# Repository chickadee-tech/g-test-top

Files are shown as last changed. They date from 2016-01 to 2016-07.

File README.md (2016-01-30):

# Chickadee Tech Generic Test Jig Top #
This is the top board to the generic test jig for Polystack **control** and **mod** boards.

## Documentation ##
See the [wiki](https://github.com/chickadee-tech/g-test-top/wiki) for documentation.

## Polystack ##
This board is part of the Polystack platform for modular microcontrol systems. More information on the platform can be found at [polystack.org](http://polystack.org).

## Support ##
If you need support with a board you own or have development questions please email support@chickadee.tech or check [chickadee.tech/support](https://chickadee.tech/support) for other ways to get support.

## Contributing ##
Please note that this project is released with a [Contributor Code of Conduct](CODE_OF_CONDUCT.md). By participating in this project you agree to abide by its terms.

### Setup ###
Components and footprints for PCB parts are not included in this repository. Instead, checkout the [chickadee-tech/kicad-libs](https://github.com/chickadee-tech/kicad-libs) repository in the same directory that this repository is checked out in. All part definitions should be relative so that they will load correctly.

### Pull requests ###
For fixes please submit a pull request to the original repository. After the pull request is merged, check the [Chickadee Tech Active Contributor Discount (ACD)](https://chickadee.tech/active-contributor) to see if you are eligible for a discount code to use on your next purchase.

### Derivatives ###
If developing your own version of the test jig top please remove all Chickadee Tech trademarks and follow the [CC-BY license](LICENSE). While not required, please consider open sourcing your modifications so others can learn from your improvements. If you do email support@chickadee.tech and we may choose to add your project to the ACD.

You may also license the Polystack logo for free by emailing support@chickadee.tech. We'll ask for your gerbers to ensure the design complies with specifications laid out [here](https://github.com/chickadee-tech/polystack/wiki) and provide written permission to use the trademark after compliance has been demonstrated.

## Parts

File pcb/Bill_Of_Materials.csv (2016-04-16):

part name | symbol | size (imp) | max current | unit price | units per build | units in stock | order total | Manufacturer ID | source url | datasheet | datasheet2
80 pin header | PORT_IN1 |  |  | $1.35 | 1 | 1 | $1.35 | DF40C-80DP-0.4V(51) | http://www.digikey.com/product-detail/en/DF40C-80DP-0.4V(51)/H11632CT-ND/1969511 | N | http://www.hirose.co.jp/cataloge_hp/ed_DF40_20140305.pdf |  | Total Base Cost | $7.13
side entry bottom 16pos 1mm | P1 |  |  | $0.92 | 1 | 0 | $0.92 | SFW16R-3STE1LF | http://www.digikey.com/product-detail/en/SFW16R-3STE1LF/609-1909-1-ND/1003194 | N |  | price ranges 1.40 - 2.50
1x8 mux | U1 | 16-VFQFN Exposed Pad |  | $0.43 | 1 | 1 | $0.43 | 74HC4051BQ,115 | http://www.digikey.com/product-detail/en/74HC4051BQ,115/568-7741-1-ND/2753885 | N | http://www.nxp.com/documents/data_sheet/74HC_HCT4051.pdf
1x16 mux | U2, U3, U4, U5 | 24-VFQFN Exposed Pad |  | $1.06 | 4 | 0 | $4.26 | 74HC4067BQ,118 | http://www.digikey.com/product-detail/en/74HC4067BQ,118/568-8885-1-ND/2813803 | N | http://www.nxp.com/documents/data_sheet/74HC_HCT4067.pdf
~3.5mm Spacer | Off Board |  |  | $0.08 | 1 | 81 | $0.08 | 908-140 | http://www.mouser.com/search/ProductDetail.aspx?R=0virtualkey0virtualkey908-140 | N | http://www.bivar.com/Portals/0/Products/d.ashx?f=/Portals/0/products/9XX-XXX.pdf
R 220 | R1, R2 | 603 |  | $0.00 | 2 | 493 | $0.01 | RC0603JR-07220RL | http://www.digikey.com/product-detail/en/yageo/RC0603JR-07220RL/311-220GRCT-ND/729688 | MF-RES-0603-220 | http://www.yageo.com/NewPortal/yageodocoutput?fileName=/pdf/R-Chip/PYu-RC_Group_51_RoHS_L_3.pdf
R 10k | R3, R4, R5, R6, R7, R8, R9, R10, R11 | 603 |  | $0.01 | 9 | 979 | $0.09 | RC0603FR-0710KL | http://www.digikey.com/product-detail/en/RC0603FR-0710KL/311-10.0KHRCT-ND/729827 | MF-RES-0603-10K | http://www.yageo.com/NewPortal/yageodocoutput?fileName=/pdf/R-Chip/PYu-RC_Group_51_RoHS_L_3.pdf

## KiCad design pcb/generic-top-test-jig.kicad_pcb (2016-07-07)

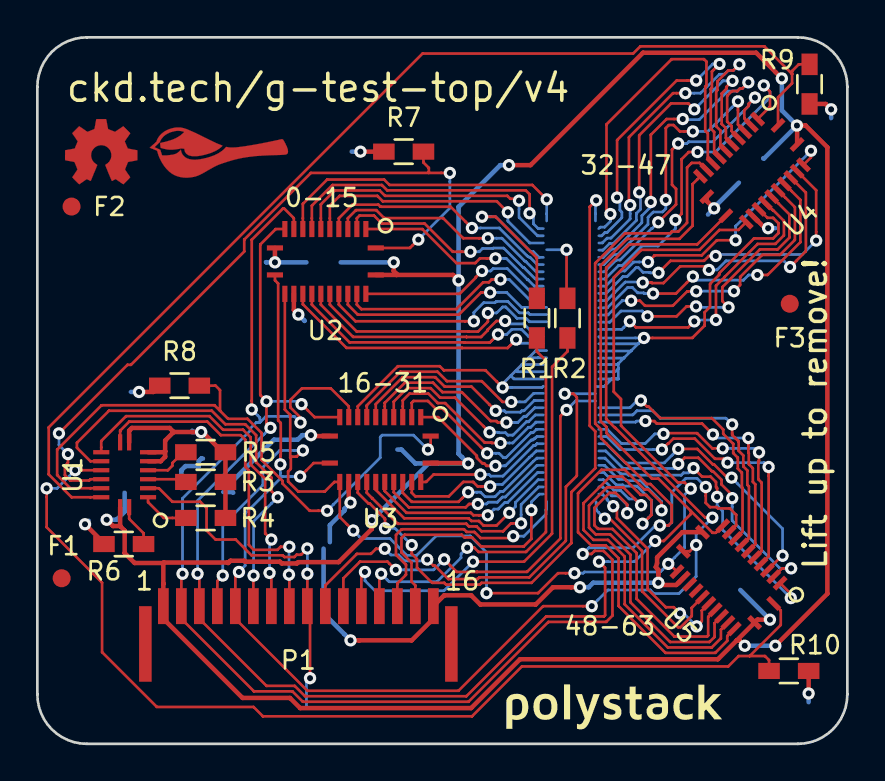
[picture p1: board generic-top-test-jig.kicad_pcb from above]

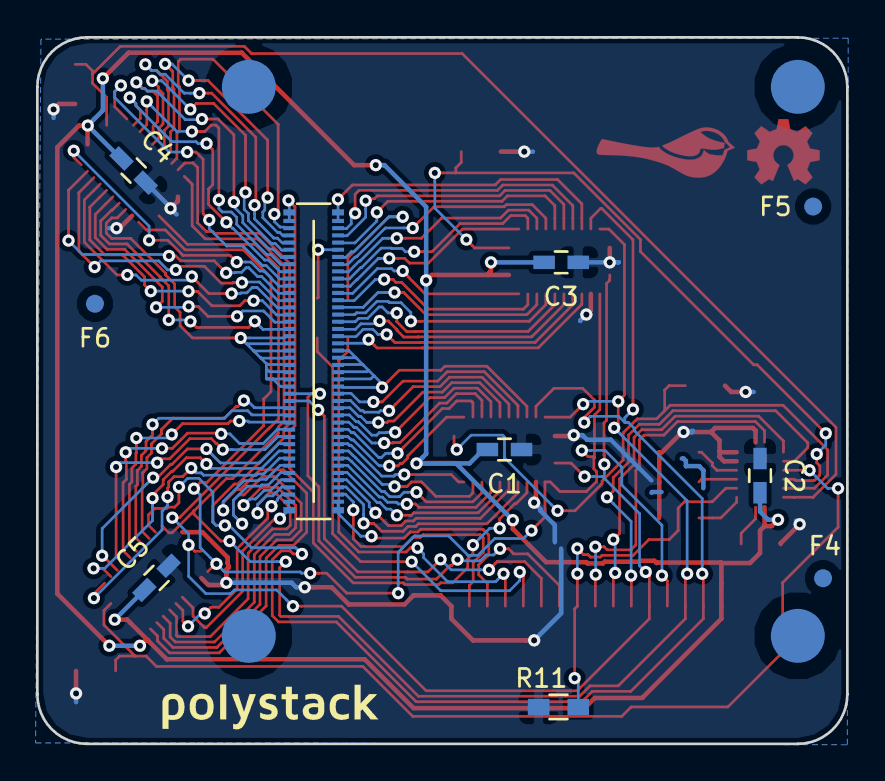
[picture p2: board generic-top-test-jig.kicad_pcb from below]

Board: 2 copper layers, 45.0 x 39.2 mm, 31 parts (11 on the bottom side), 88 nets.

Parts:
C1, C2, C3, C4, C5: 0.1uF; C_0603_HandSoldering
F1, F2, F3, F4, F5, F6: 1mm; Fiducial
P1: CONN_01X16; SFW12LF-16pin
PORT_IN1: CKD_SANDWICH; DF40-80pin-Header
R1, R2: 220; R_0603_HandSoldering
R3, R4, R5, R6, R7, R8, R9, R10, R11: 10k; R_0603_HandSoldering
U1: 74HC4051; SOT763-1(DHVQFN16)
U2, U3, U4, U5: 74HC4067; DHVQFN24
svg2mod, svg2mod#2: G***; polystack-bold-0.625

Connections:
+5V: C1.2, C2.2, C3.2, C4.1, C5.1, P1.1, U1.16, U2.24, U3.24, U4.24, U5.24
/3V3_0.3A_E: PORT_IN1.17, U2.17
/3V3_0.3A_LL: PORT_IN1.16, U2.18
/5V: PORT_IN1.19, PORT_IN1.20, PORT_IN1.21, PORT_IN1.22, PORT_IN1.23, PORT_IN1.24, U3.9
/+BATT: PORT_IN1.18, U2.16
/ADC1: PORT_IN1.49, U4.2
/ADC2: PORT_IN1.50, U4.23
/BOOT: P1.10, PORT_IN1.65
/CAN_HI: PORT_IN1.67, U5.9
/CAN_LO: PORT_IN1.68, U5.8
/GND: PORT_IN1.57, PORT_IN1.58, PORT_IN1.59, PORT_IN1.60, PORT_IN1.61, PORT_IN1.62, PORT_IN1.63, PORT_IN1.64, U4.16
/GPIO3: PORT_IN1.7, U2.5
/GPIO4: PORT_IN1.8, U2.4
/GPIO5: PORT_IN1.9, U2.3
/GPIO6: PORT_IN1.10, U2.2
/HEIGHT_1: PORT_IN1.15, U2.19
/HEIGHT_2: PORT_IN1.14, U2.20
/HEIGHT_4: PORT_IN1.13, U2.21
/RESET: P1.11, PORT_IN1.66
/RX: P1.14, PORT_IN1.40
/S0: P1.2, U2.10, U3.10, U4.10, U5.10
/S1: P1.3, U2.11, U3.11, U4.11, U5.11
/S2: P1.4, U2.14, U3.14, U4.14, U5.14
/S3: P1.5, U2.13, U3.13, U4.13, U5.13
/S4: P1.6, U1.11
/S5: P1.7, U1.10
/S6: P1.8, U1.9
/SDMMC1_CK: PORT_IN1.55, U4.18
/SDMMC1_CMD: PORT_IN1.56, U4.17
/SDMMC1_D0: PORT_IN1.51, U4.22
/SDMMC1_D1: PORT_IN1.52, U4.21
/SDMMC1_D2: PORT_IN1.53, U4.20
/SDMMC1_D3: PORT_IN1.54, U4.19
/SPI1_MISO: PORT_IN1.79, U5.19
/SPI1_MOSI: PORT_IN1.80, U5.18
/SPI1_NSS: PORT_IN1.77, U5.21
/SPI1_SCK: PORT_IN1.78, U5.20
/SPI2_MISO: PORT_IN1.75, U5.23
/SPI2_MOSI: PORT_IN1.76, U5.22
/SPI2_NSS: PORT_IN1.73, U5.3
/SPI2_SCK: PORT_IN1.74, U5.2
/SPI3_MISO: PORT_IN1.71, U5.5
/SPI3_MOSI: PORT_IN1.72, U5.4
/SPI3_NSS: PORT_IN1.69, U5.7
/SPI3_SCK: PORT_IN1.70, U5.6
/SWCLK: PORT_IN1.6, R1.2
/SWDIO: PORT_IN1.5, R2.2
/TIM1: PORT_IN1.1, U2.9
/TIM2: PORT_IN1.2, U2.8
/TIM3: PORT_IN1.3, U2.7
/TIM4: PORT_IN1.4, U2.6
/TIMG1_CH1: PORT_IN1.41, U3.16
/TIMG1_CH2: PORT_IN1.42, U4.9
/TIMG1_CH3: PORT_IN1.43, U4.8
/TIMG1_CH4: PORT_IN1.44, U4.7
/TIMG2_CH1: PORT_IN1.45, U4.6
/TIMG2_CH2: PORT_IN1.46, U4.5
/TIMG2_CH3: PORT_IN1.47, U4.4
/TIMG2_CH4: PORT_IN1.48, U4.3
/TX: P1.15, PORT_IN1.39
/UART2_RX: PORT_IN1.38, U3.17
/UART2_TX: PORT_IN1.37, U3.18
/UART3_RX: PORT_IN1.36, U3.19
/UART3_TX: PORT_IN1.35, U3.20
/UART4_RX: PORT_IN1.34, U3.21
/UART4_TX: PORT_IN1.33, U3.22
/UART5_RX: PORT_IN1.32, U3.23
/UART5_TX: PORT_IN1.31, U3.2
/UART6_RX: PORT_IN1.30, U3.3
/UART6_TX: PORT_IN1.29, U3.4
/UART7_RX: PORT_IN1.28, U3.5
/UART7_TX: PORT_IN1.27, U3.6
/UART8_RX: PORT_IN1.26, U3.7
/UART8_TX: PORT_IN1.25, U3.8
/Z: P1.9, R11.2, U1.3
/Z0: R7.2, U1.13, U2.1
/Z1: R8.2, U1.14, U3.1
/Z2: R9.2, U1.15, U4.1
/Z3: R10.2, U1.12, U5.1
/i2c_SCL: PORT_IN1.12, U2.22
/i2c_SDA: PORT_IN1.11, U2.23
GNDPWR: C1.1, C2.1, C3.1, C4.2, C5.2, P1.16, R3.1, R4.1, R5.1, R6.1, R7.1, R8.1, R9.1, R10.1, R11.1, U1.6, U1.7, U1.8, U2.12, U2.15, U3.12, U3.15, U4.12, U4.15, U5.12, U5.15
unnamed: P1.12, R2.1
unnamed: P1.13, R1.1
unnamed: R3.2, U1.4
unnamed: R4.2, U1.2
unnamed: R5.2, U1.5
unnamed: R6.2, U1.1

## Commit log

2016-01-26 Top board of test jig.
    [ExpansionPort.sch, generic-top-test-jig.kicad_pcb, generic-top-test-jig.sch]
2016-01-30 Gerbers for v1 of the test jig.
    [Bill_Of_Materials.csv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]
2016-03-05 Generic Test Jig Top v2 which correct Vee input in 8-way mux and changes SWD pins.
    Also:
    * Switches to thinner FlightStack logo.
    * Adds OSHW logo.
    [generic-top-test-jig-B.Cu.gbl, generic-top-test-jig-B.Mask.gbs, generic-top-test-jig-B.SilkS.gbo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]
2016-04-07 Add decoupling caps.
    [generic-top-test-jig.kicad_pcb, generic-top-test-jig.sch]
2016-04-13 Rebrand everything to Polystack and increment versions.
    [generic-top-test-jig.kicad_pcb, generic-top-test-jig.sch]
2016-04-16 Final gerbers for test manufacturing run.
    [Bill_Of_Materials.csv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]
2016-06-07 Update polystack logo to bold variant and bump version number.
    [generic-top-test-jig.kicad_pcb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]
2016-07-07 Add license information to many files. PCB design files are CC-BY and code is MIT license.
    [generic-top-test-jig.kicad_pcb, generic-top-test-jig.sch]
2016-07-07 Convert to relative component and footprint paths.
    [ExpansionPort.sch, generic-top-test-jig.sch]

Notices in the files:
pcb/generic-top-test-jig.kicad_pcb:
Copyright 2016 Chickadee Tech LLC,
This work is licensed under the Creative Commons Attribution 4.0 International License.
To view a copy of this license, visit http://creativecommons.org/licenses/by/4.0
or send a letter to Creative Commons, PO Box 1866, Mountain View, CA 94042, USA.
